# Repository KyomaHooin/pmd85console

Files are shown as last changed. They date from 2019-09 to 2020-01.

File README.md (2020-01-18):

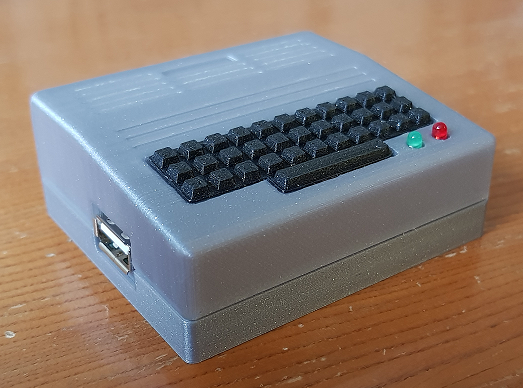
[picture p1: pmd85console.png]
CONSOLE console


DESCRIPTION

Raspberry Pi 1A+ Tesla PMD-85 retro console powered by modified Petr Tůma <a href="https://github.com/ceresek/simpmd">simpmd</a> (c) 2008.

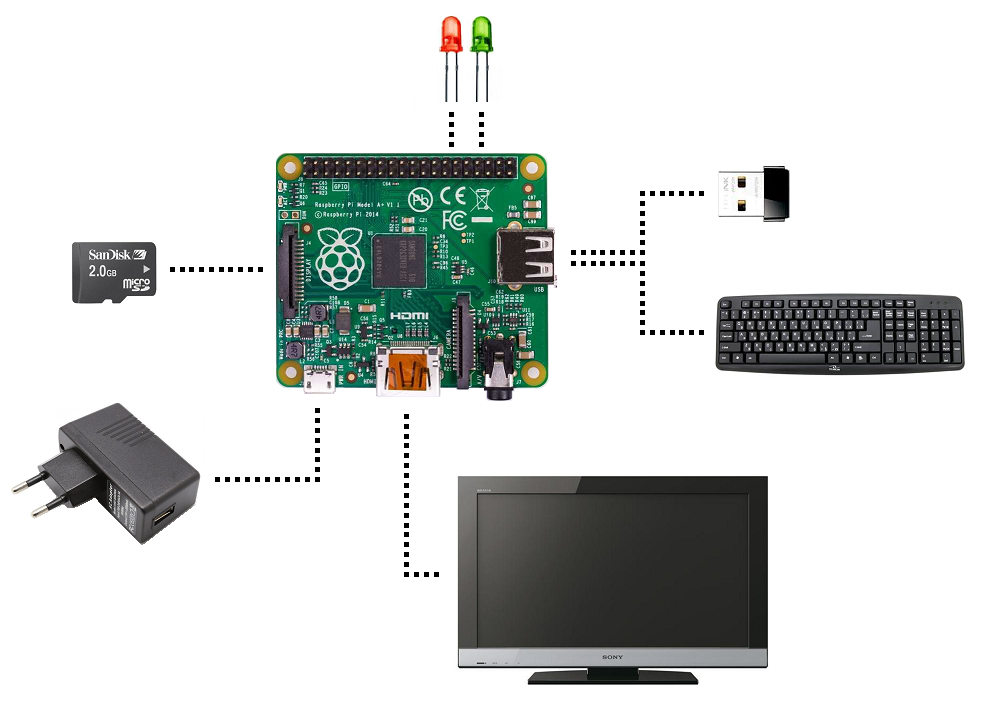
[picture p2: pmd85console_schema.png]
SCHEMA schema


SCREEN

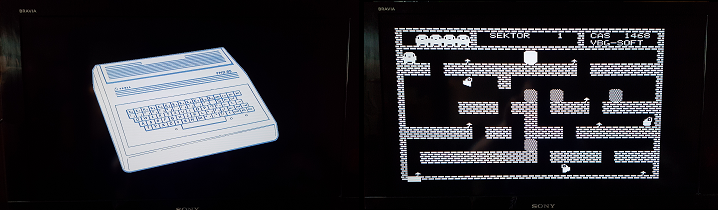
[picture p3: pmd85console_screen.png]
SCREEN screen


TODO

- Remove hardcoded paths.
- Menu scroll game preview.
- Fix sound.
- Fix window/renderer duplication.

BUG

- `snd flood alsa lib pcm.c:(snd_pcm_recover) underrun occured`
- `mesa loader: failed to retrieve device information`

HARDWARE

<pre>
1x <a target="_blank" href="http://rpishop.cz/248-raspberry-pi-1a">Raspberry</a> (1A+)
1x <a target="_blank" href="https://www.ges.cz/cz/usb-napajec-napajeci-adapter-mw-5v-1-2a-sun-usb-GES07507424.html">Power adapter</a> (5V 1.2A)
1x <a target="_blank" href="https://www.mironet.cz/edimax-wireless-nano-usb-20-adapter-80211n-150mbps-sw-wps+dp117994/">USB Wifi dongle</a> (RTL8188CUS/50-75mA)
1x <a target="_blank" href="https://www.czc.cz/gembird-cablexpert-kabel-hdmi-hdmi-0-5m-1-4-m-m-stineny-zlacene-kontakty-cerna/248060/produkt">HDMI cable</a> (0.5m)
1x <a target="_blank" href="https://www.alza.cz/roline-usb-2-0-usb-am-micro-usb-bm">Micro USB cable</a> (1m)
1x <a target="_blank" href="https://www.aliexpress.com/item/New-High-Quality-USB-To-TTL-Serial-Module-FTDI-FT232RL-USB-3-3V-5V-To-TTL/32971767031.html">USB FTDI TTL/UART</a> (3.3V 6-pin)
1x MicroSD (2GB)
1x Keyboard (Chicony KU-0108s/100mA)
1x <a target="_blank" href="https://www.ges.cz/cz/l-934gd-GES10700054.html">Green LED</a> (3mm 10mA 2.2V)
1x <a target="_blank" href="https://www.ges.cz/cz/l-934id-GES10701762.html">Red LED</a> (3mm 10mA 2V)
1x <a target="_blank" href="https://www.ges.cz/cz/rm0207-120r-1-GES05300318.html">Resistor 120R</a>
1x <a target="_blank" href="https://www.ges.cz/cz/rm0207-150r-1-GES05300319.html">Resistor 150R</a>
1x <a target="_blank" href="https://www.ges.cz/cz/bls-02-GES06614037.html">BLS 02</a>
2x <a target="_blank" href="https://www.ges.cz/cz/bls-01-GES06614525.html">BLS 01</a>
4x <a target="_blank" href="https://www.ges.cz/cz/bls-contacts-GES06614047.html">BLS contact</a>
1x <a target="_blank" href="https://www.ges.cz/cz/liyv-14-bl-GES06913880.html">Copper Wire</a> (0.14mm 1m)
4x <a target="_blank" href="https://www.ges.cz/cz/esst-m2-2x6-GES06814889.html">Screw</a> (M2.2x6mm)
</pre>

RPI

<pre>
wget --no-check-certificate https://downloads.raspberrypi.org/raspbian_lite_latest
# umount & write SD card / SD reader[!]
umount /dev/sdX[12] 2>/dev/null
unzip -p 2018-11-13-raspbian-stretch-lite.zip | dd of=/dev/sdX bs=4M

touch /boot/ssh
cat << EOF >> /boot/wpa_supplicant.conf
country=CZ
ctrl_interface=DIR=/var/run/wpa_supplicant GROUP=netdev
update_config=1
network={
	ssid="Wireless LAN"
	scan_ssid=1
	psk="cleartext"
	key_mgmt=WPA-PSK
}
EOF

raspi-config > Advanced > GL Driver > Enable Fake KMS

apt-get update
apt-get install libgl1-mesa-dri

raspi-config > Advanced > GPU mem > 128
raspi-config > Advanced > Overclocking > Medium

dphys-swapfile swapoff
dphys-swapfile uninstall

systemctl disable avahi-daemon bluetooth paxctld rsync triggerhappy triggerhappy.socket nfs-client.target \
                  systemd-timesyncd apt-daily apt-daily.timer apt-daily-upgrade apt-daily-upgrade.timer \
                  dphys-swapfile networking dhcpcd ssh getty@tty1 rc-local wifi-country keyboard-setup \
                  alsa-restore systemd-rfkill

cp raspberry/pmd85.service /etc/systemd/system/
systemctl enable pmd85.service

apt-get install vim mc ntpdate

/etc/fstab:
tmpfs	/tmp	tmpfs	defaults,noatime,nosuid,size=5m	0	0
tmpfs	/var/log	tmpfs	defaults,noatime,nosuid,mode=0755,size=5m	0	0

/etc/dhcpcd.conf:
interface wlan0
static ip_address=192.168.0.85/24
static routers=192.168.0.1
static domain_name_servers=xx.xx.xx.xx xx.xx.xx.xx
</pre>

UART

<pre>
3.3V UART => | x | x | GND | TX | RX | ..
             | x | x |  x  | x  | x  | ..

minicom -D /dev/ttyUSB0 -b 115200

[Ctrl] > [A] > [Z] > [O] > Serial port setup > [F]low control > Off
</pre>

LED

<pre name="led">
.. |  x  | x | x | x |  x  | x | x | x | GND | 16 | x | x |
.. | 3v3 | x | x | x | GND | x | x | x |  x  | x  | x | x |

           [RED]                    [GREEN]
            | |                       | |
     150R --  |                120R --  |
     [BGB]     -- 3.3V[17]     [BRB]     -- GPIO16[36]
       |                         |
      GND[25]                   GND[34]

/boot/config.txt:
# PWR LED(disable onboard)
dtparam=pwr_led_trigger=none
dtparam=pwr_led_activelow=off

# ACT LED GPIO16[36]
dtparam=act_led_gpio=16
dtparam=act_led_trigger=cpu
</pre>

PLYMOUTH

<pre>
apt-get install plymouth plymouth-themes -> 0.9.4-1.1(Buster)

cp -r theme-pmd85 /usr/share/plymouth/themes/

plymouth-set-default-theme -R theme-pmd85

/usr/share/plymouth/plymouthd.defaults:
DeviceTimout=10

systemctl disable plymouth-start -> Shutdown/reboot only.

/boot/cmdline.txt:
logo.nologo quiet splash plymouth.ignore-serial-consoles vt.global_cursor_default=0

/boot/config.txt:
boot_delay=0
</pre>

SDL2

<pre>
wget --no-check-certificate https://www.libsdl.org/release/SDL2-2.0.9.tar.gz

apt-get install libgles2-mesa-dev libgbm-dev libudev-dev libasound2-dev liblzma-dev

autogen.sh
./configure --enable-video-kmsdrm --disable-video-opengl --disable-video-x11 --disable-video-rpi
make
make install

wget --no-check-certificate https://www.libsdl.org/projects/SDL_ttf/release/SDL2_ttf-2.0.15.tar.gz
autogen.sh
./configure
make
make install
</pre>

SIMPMD

<pre>
make clean
make
</pre>

FILE

<pre>
                buster/ - Raspbian "Buster" install instructions by Jozef Říha - <a href="https://github.com/jose1711">jose1711</a>.
              openscad/ - 3D printable retro case.
             raspberry/ - Raspbery support scripts.
                simpmd/ - Modified SDL2 PMD-85 emulator source code by Petr Tůma (c) 2008.
           theme-pmd85/ - Splash Plymouth theme.

       pmd85console.png - Retro console final.
pmd85console_schema.png - Retro console schematics.
      atari-classic.ttf - TTF font by Mark Simonson (c) 2016.
</pre>

SOURCE

https://github.com/KyomaHooin/pmd85console

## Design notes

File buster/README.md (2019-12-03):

Install Raspbian using Noobs (https://www.raspberrypi.org/downloads/noobs/)
<pre>
# do these steps on a Linux system with an SD card inserted into a card reader
# all data on the card will be erased thus make sure you have a backup!
# at least 8GB SD card is recommended

# get the latest raspbian lite
wget https://downloads.raspberrypi.org/raspbian_lite_latest

# check target device (sd card) and set target variable accordingly
lsblk | grep ^sd
target=sdXY
sudo umount /dev/${target}*
unzip -p raspbian_lite_latest | pv | sudo dd of=/dev/${target} bs=4M
sudo mount /dev/${target}1 /mnt
sudo touch /mnt/ssh
# configure wifi if wired ethernet is not present
cat << EOF >> /mnt/wpa_supplicant.conf
country=CZ
ctrl_interface=DIR=/var/run/wpa_supplicant GROUP=netdev
update_config=1
network={
ssid="Wireless LAN"
scan_ssid=1
psk="cleartext"
key_mgmt=WPA-PSK
}
EOF
sudo umount /mnt
# remove the card from the reader, put into Raspi and boot from it
</pre>
Recompile SDL2 with KMS support
<pre>
# log in to raspberry pi (user: pi, password: raspberry) via SSH
# and change default password
passwd

sudo vi /etc/apt/sources.list
# uncomment deb-src in /etc/apt/sources.list

# do system update
sudo apt-get update
sudo apt-get upgrade
# install packages necessary to rebuild SDL with KMS enabled
sudo apt-get install devscripts build-essential libgbm-dev libgl1-mesa-dri git
sudo apt-get build-dep libsdl2

# install vim, mc and ntpdate (optional)
apt-get install vim mc ntpdate

# pull libsdl2 sources and rebuild
apt-get source libsdl2
cd libsdl2*/
sed -i '/enable-video-wayland/s/$/ --enable-video-kmsdrm --disable-video-opengl --disable-video-x11 --disable-video-rpi/' debian/rules
debuild -- clean
debuild -us -uc

# install KMS-enabled libsdl2
sudo dpkg -i ../libsdl2*.deb
sudo apt-mark hold sdl2-2.0.0 libsdl2-doc
</pre>
Performance tuning
<pre>
# disable swap
dphys-swapfile swapoff
dphys-swapfile uninstall

# turn-off unnecessary services
systemctl disable avahi-daemon bluetooth paxctld rsync triggerhappy triggerhappy.socket nfs-client.target \
                  systemd-timesyncd apt-daily apt-daily.timer apt-daily-upgrade apt-daily-upgrade.timer \
                  dphys-swapfile rc-local wifi-country keyboard-setup systemd-rfkill getty@tty1 exim4

# in case you have a chance to use UART for debugging, disable networking for faster boot
systemctl disable networking dhcpcd ssh systemd-timesyncd wpa_supplicant
</pre>
Additional configuration
<pre>
# Enable fake KMS
sudo raspi-config # > Advanced > GL Driver > Enable Fake KMS

# Change memory split and overclock
sudo raspi-config # > Advanced > GPU mem > 128
sudo raspi-config # > Overclocking > Medium

# use /tmp and /var/log as in-memory filesystems
echo "
tmpfs    /tmp      tmpfs    defaults,noatime,nosuid,size=5m            0  0
tmpfs    /var/log  tmpfs    defaults,noatime,nosuid,mode=0755,size=5m  0  0
" | sudo tee -a /etc/fstab

# reboot
</pre>
Compile and install simpmd
<pre>
# clone pmd85console project
git clone https://github.com/KyomaHooin/pmd85console.git

# compile modified simpmd
cd pmd85console/simpmd
# install dependencies
sudo apt install libghc-sdl2-ttf-dev
make PMD_BUILD=RELEASE PMD_SHARE=/usr/share/simpmd/

sudo cp bin/mem2raw bin/ptp2raw bin/rawinfo bin/simpmd /usr/bin
sudo install -dm755 /usr/share/simpmd
sudo cp data/roms/M* /usr/share/simpmd
sudo cp data/font/atari-classic.ttf /usr/share/simpmd
sudo cp data/logo/* /usr/share/simpmd
sudo cp data/tapes/games-pmd1/* /usr/share/simpmd
sudo cp data/tapes/games-pmd2/* /usr/share/simpmd
</pre>
Install Plymouth and customize boot
<pre>
sudo apt-get install plymouth plymouth-themes
sudo cp -r ~/pmd85console/theme-pmd85 /usr/share/plymouth/themes/
sudo plymouth-set-default-theme -R theme-pmd85
sudo sed -i '/DeviceTimeout=/s/.*/DeviceTimeout=10/' /usr/share/plymouth/plymouthd.defaults
sudo sudo systemctl disable plymouth-start
sudo sed -i '1s/$/ logo.nologo quiet splash plymouth.ignore-serial-consoles vt.global_cursor_default=0/' /boot/cmdline.txt
echo "boot_delay=0" | sudo tee -a /boot/config.txt
sudo cp ~/pmd85console/raspberry/pmd85.service /etc/systemd/system
sudo systemctl enable pmd85.service
</pre>

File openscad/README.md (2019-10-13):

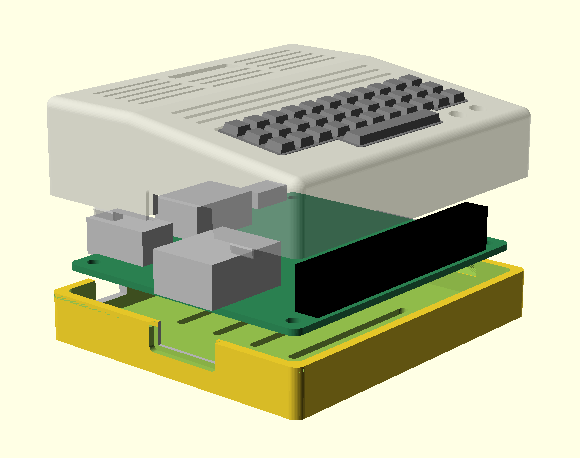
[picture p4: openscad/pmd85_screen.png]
CASE case


DESCRIPTION

Raspberry Pi 1A+ PMD-85 retro console 3D case.

FILES

<pre>
pmd85_bottom.stl - Case bottom part STL file.
   pmd85_top.stl - Case top part STL file.
    keyboard.stl - Keyboard STL file.

      pmd85.scad - Main 3D case.
        rpi.scad - Raspberry 1A+ model.
        mod.scad - Model functions.

pmd85_screen.png - Model screenshot.
</pre>

SOURCE

https://github.com/KyomaHooin/pmd85console

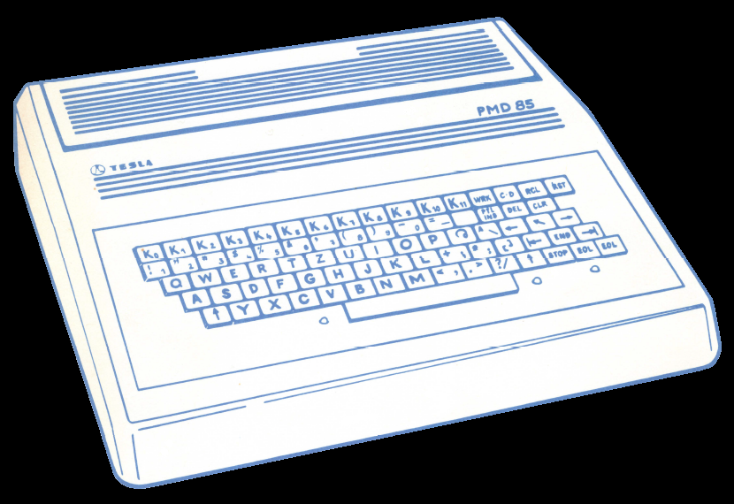
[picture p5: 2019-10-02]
theme-pmd85/pmd85_830_570.png

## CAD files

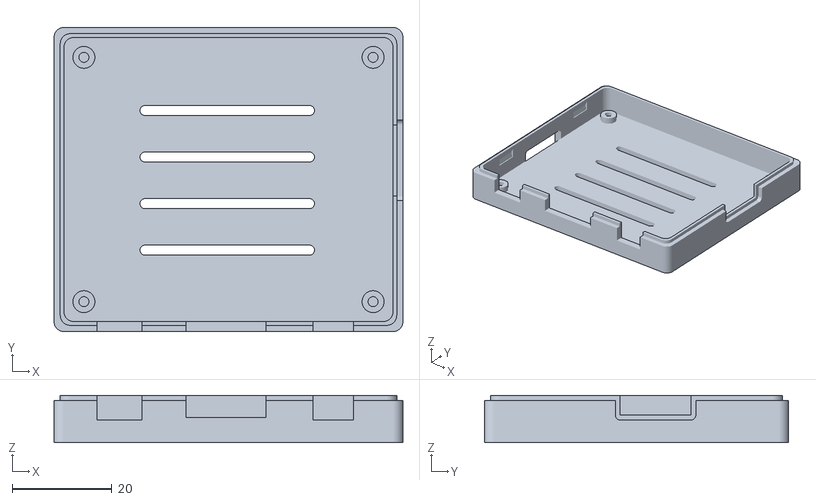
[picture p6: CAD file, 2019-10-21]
openscad/pmd85_bottom.stl
70.0 x 61.0 x 9.47

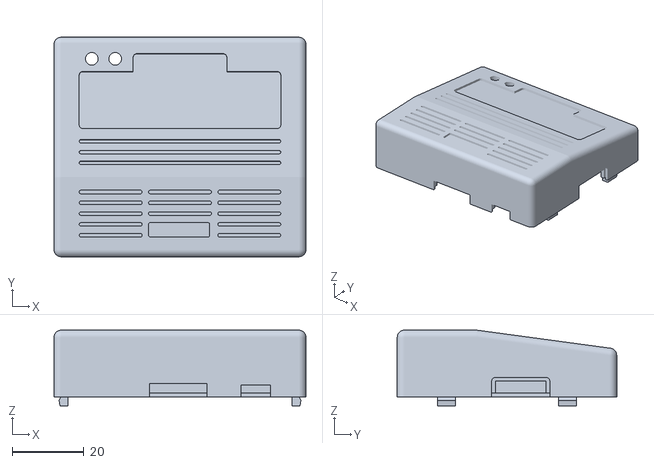
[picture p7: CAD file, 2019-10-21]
openscad/pmd85_top.stl
70.0 x 61.0 x 21.0

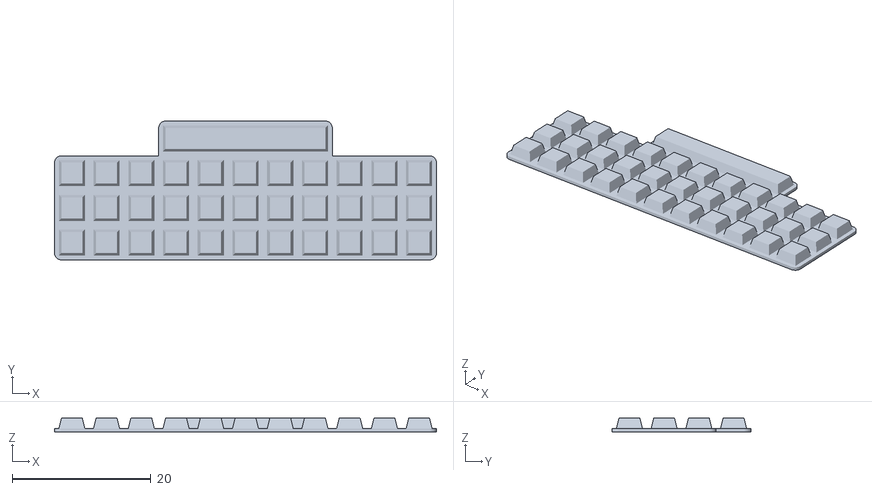
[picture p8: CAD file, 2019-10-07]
openscad/keyboard.stl
55.0 x 20.0 x 2.00

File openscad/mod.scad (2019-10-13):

//
// PMD-85 retro console mods
//

module bottom_hull(x,y,z) {
    hull() {
        cylinder(r=2,h=z);
        translate([x,0,0]) cylinder(r=2,h=z);
        translate([x,y,0]) cylinder(r=2,h=z);
        translate([0,y,0]) cylinder(r=2,h=z);
    }
}

module bottom_base() {
    difference() {
            bottom_hull(bottomX,bottomY,bottomHeight+1);// +1 = lip lock cut
            translate([bottomThick,bottomThick,bottomThick]) bottom_hull(bottomX-4,bottomY-4,bottomHeight+1);// +1 = lip lock cut
        }
    }

module bottom_lip_lock() {
    difference() {
        bottom_hull(bottomX,bottomY,1);
        translate([1.25,1.25,-1]) bottom_hull(bottomX-2.5,bottomY-2.5,3);
    }
}

module top_lip_lock() {
        translate([0.75,0.75,0]) bottom_hull(bottomX-1.5,bottomY-1.5,1);
}

module bottom_vent() {
    hull() {
        cylinder(r=1,h=2*bottomThick);
        translate([bottomX/2,0,0]) cylinder(r=1,h=2*bottomThick);
    }
}

module bottom_mount(offsetX,offsetY,Thick) {
    difference() {
        translate([offsetX, offsetY, Thick]) cylinder(h=bottomMountHeight, d=bottomMountDia);
        translate([offsetX, offsetY, Thick-1]) cylinder(h=bottomMountHeight+2, d=2);
    }
}

module sd_lip() {
    translate([0,0,cardHeight+bottomThick])
    rotate([0,90,0])
    hull() {
      cylinder(r=1,h=3);
      translate([0,cardWidth,0]) cylinder(r=1,h=3);
      translate([0,-1,0])cube([cardHeight+bottomThick,cardWidth+2,3]);
    }
}


module usb_lip(){
    rotate([90,0,90])
    hull() {
        cylinder(r=1,h=2);
        translate([usbWidth,0,0]) cylinder(r=1,h=2);
        translate([usbWidth,usbHeight,0]) cylinder(r=1,h=2);
        translate([0,usbHeight,0]) cylinder(r=1,h=2);
    }
}

module top_poly(x,y,h1,h2,rom) {
    minkowski(){
        polyhedron(
            points= [
                [0,0,0], //0
                [x,0,0], //1
                [x,y,0], //2
                [0,y,0], //3
                [0,0,h1], //4
                [x,0,h1], //5
                [x,rom,h1], //6
                [x,y,h2], //7
                [0,y,h2], //8
                [0,rom,h1] //9
            ],
            faces = [
                [0,1,2,3], //bottom
                [4,5,1,0], //back
                [5,6,7,2,1], // left
                [7,8,3,2], // front
                [8,9,4,0,3], // right
                [4,9,6,5], // top-A
                [9,8,7,6] // top-B
            ]
        );
        sphere(2);
    }
}

module top_base() {
   difference() {
   top_poly(topX,topY,topBackHeight,topFrontHeight,topRom);// BASE
   translate([2,2,0])top_poly(topX-4,topY-4,topBackHeight-2,topFrontHeight-2,topRom-2);// FILL
   translate([-2,-2,-3])cube([topX+4,topY+4,3]);// CUT
   }
}

module key_poly(x1,y1,x2,y2,h) {
        polyhedron(
            points= [
                [0,0,0], //0
                [x1,0,0], //1
                [x1,y1,0], //2
                [0,y1,0], //3
                [(x1-x2)/2,(y1-y2)/2,h], //4
                [x2+(x1-x2)/2,(y1-y2)/2,h], //5
                [x2+(x1-x2)/2,y2+(y1-y2)/2,h], //6
                [(x1-x2)/2,y2+(y1-y2)/2,h], //7
            ],
            faces = [
                [0,1,2,3], //bottom
                [4,5,1,0], //back
                [5,6,2,1], // left
                [6,7,3,2], // front
                [7,4,0,3], // right
                [7,6,5,4], // top
            ]
        );
}

module kbd_slab() { //56x26
    minkowski() {
    union() {
        cube([54,14,1]);//key base 56x16cm
        translate([30/2,14,0]) cube([24,5,1]);//spacebar base 26x6mm
    }
    cylinder(r=1);
    }
}

module vent_slab() {// 55x1
    hull() {
        translate([0,0,0])cylinder(r=0.5);
        translate([55,0,0])cylinder(r=0.5);
    }
}

module vent_slab_short() {
    hull() {
        translate([0.5,0.5,0])cylinder(r=0.5);
        translate([17,0.5,0])cylinder(r=0.5);
    }
}

module vent_slab_big() {
    translate([0.5,0.5,0])
    minkowski() {
        cube([16,3,1]);
        cylinder(r=0.5);
    }
}

module clip_hole() {// 1x5x4
    translate([-0.5,0,-1.5])
    difference(){
    polyhedron(
        points = [
            [1,0,0],//0
            [1,6,0],//1
            [0+0.5,0,3],//2
            [0+0.5,6,3],//3
            [1,0,4],//4
            [1,6,4] //5
    ],
        faces = [
            [3,2,0,1],
            [3,1,5],
            [4,5,1,0],
            [2,4,0],
            [4,2,3,5]
    ]
    );
    translate([0,-1,0])cube([2,8,1.5]);
    }
}

module clip() {
    difference(){
    union() {
    translate([0,0,3])cube([2,5,8]);
    polyhedron(
        points = [
            [0,0,0],//0
            [0,5,0],//1
            [0,0,3],//2
            [2,0,3],//3
            [2,5,3],//4
            [0,5,3] //5
    ],
        faces = [
            [2,3,0],
            [3,4,1,0],
            [5,1,4],
            [2,0,1,5],
            [2,5,4,3]
    ]
    );
    translate([-1,0,7])
    polyhedron(
        points = [
            [1,0,0],//0
            [1,5,0],//1
            [0+0.5,0,1],//2
            [0+0.5,5,1],//3
            [1,0,4],//4
            [1,5,4] //5
    ],
        faces = [
            [4,0,2],
            [4,5,1,0],
            [3,1,5],
            [4,2,3,5],
            [2,0,1,3]
    ]
    );
    }
    translate([-1,-1,11-1.5])cube([4,7,2]);// clip cut
    }
}

module clip_back() {
    translate([2,0,11-1.5])// clip cut
    rotate([0,180,0]) clip();
}

module clip_front() {
    translate([0,5,11-1.5])// clip cut
        rotate([0,180,180]) clip();
}

module clip_hole_front() {
    clip_hole();
}

module clip_hole_back() {
    translate([0.5,6,0])
        rotate([0,0,180]) clip_hole();
}

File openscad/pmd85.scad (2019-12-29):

//
// Retro PMD-85 console printable 3D case.
//

include <mod.scad>;
include <rpi.scad>;

drawCaseBottom=0;
drawCaseTop=0;
drawPi=0;
drawKeyboard=0;
drawAll=1;

//--------------------------------------

$fn=50;

//--------------------------------------

bottomThick=2;
bottomX=piX+1;
bottomY=piY+1;
bottomMountHeight=1.75;
bottomMountDia=4.4;
bottomHeight=bottomThick+bottomMountHeight+piThick+microHeight-0.5;

//--------------------------------------

topThick=bottomThick;
topX=piX+1;
topY=piY+1;
topBackHeight=25-bottomHeight;
topFrontHeight=20-bottomHeight;;
topRom=20;

angle = atan(5/37);
function angle_coord(x,a,thick) = -(5*x)/37 + 1025/37 + thick * tan(a)/sin(a);

//------------------------------
//
//KBD
//

module keyboard() {//55x15x2
    minkowski() {
      union() {
        cube([53,13,0.5]);//key base 55x15cm
        translate([30/2,14,0]) cube([23,4,0.5]);//spacebar base 25x5mm
      }
    cylinder(r=1);
    }
    for (fx=[0:10])
        for (fy=[0:2])
            translate([-0.5+fx*5,-0.5+fy*5,1]) key_poly(4,4,3,3,2); // key 4x4mm
    translate([30/2-0.5,0.5+14,1])key_poly(24,4,23,3,2); // spacebar 24x4mm
}

//------------------------------
//
// TOP
//

module case_top() {
    union() {
    difference() {
    top_base();
    //RPI
    translate([0.5,0.5,-piThick-microHeight+0.5])rpi(edge=2);
    //KBD SLAB
    translate([(topX-55)/2+0.5,34.5,angle_coord(34.5,angle,-7.25)])
        rotate([-angle,0,0]) kbd_slab();
    //VENT SLAB SLIDE
    translate([(topX-55)/2,30,angle_coord(30,angle,-7.1)]) rotate([-angle,0,0]) vent_slab();
    translate([(topX-55)/2,27,angle_coord(27,angle,-7.1)]) rotate([-angle,0,0]) vent_slab();
    translate([(topX-55)/2,24,angle_coord(24,angle,-7.1)]) rotate([-angle,0,0]) vent_slab();
    //VENT SLAB TOP
    translate([(topX-56)/2,15.5,topBackHeight+1.25]) vent_slab_short();
    translate([(topX-56)/2,12.5,topBackHeight+1.25]) vent_slab_short();
    translate([(topX-56)/2,9.5,topBackHeight+1.25]) vent_slab_short();
    translate([(topX-56)/2,6.5,topBackHeight+1.25]) vent_slab_short();
    translate([(topX-56)/2,3.5,topBackHeight+1.25]) vent_slab_short();
    translate([(topX-56)/2+15+(54-30-15.5)/2,9.5,topBackHeight+1.25]) vent_slab_short();
    translate([(topX-56)/2+15+(54-30-15.5)/2,12.5,topBackHeight+1.25]) vent_slab_short();
    translate([(topX-56)/2+15+(54-30-15.5)/2,15.5,topBackHeight+1.25]) vent_slab_short();
    translate([(topX-56)/2 + 54-15.5,15.5,topBackHeight+1.25]) vent_slab_short();
    translate([(topX-56)/2 + 54-15.5,12.5,topBackHeight+1.25]) vent_slab_short();
    translate([(topX-56)/2 + 54-15.5,9.5,topBackHeight+1.25]) vent_slab_short();
    translate([(topX-56)/2 + 54-15.5,6.5,topBackHeight+1.25]) vent_slab_short();
    translate([(topX-56)/2 + 54-15.5,3.5,topBackHeight+1.25]) vent_slab_short();
    translate([(topX-56)/2 +15+(54-30-15.5)/2,3.5,topBackHeight+1.25]) vent_slab_big();
    //LED HOLE
    translate([15,53,10]) cylinder(d=3.5,h=10);
    translate([8.5,53,10]) cylinder(d=3.5,h=10);
    // USB LIP
    translate([topX+1.25,piY-usbY-usbWidth+1,-microHeight+0.5+0.5]) usb_lip();
    //LIP LOCK
    top_lip_lock();
    }
    // CLIP
    translate([0-0.1,topY/4-5,-2.5])clip_front();
    translate([0-0.1,topY-topY/4,-2.5])clip_front();
    translate([topX-2+0.1,topY/4-5,-2.5])clip_back();
    translate([topX-2+0.1,topY-topY/4,-2.5])clip_back();
    }
    //KBD
    //color("grey")
    //translate([(topX-53)/2,35,angle_coord(35,angle,-8)]) rotate([-angle,0,0]) keyboard();
}

//------------------------------
//
// BOTTOM
//

module case_bottom() {
    difference() {
        //BASE
        bottom_base();
        //VENT
        for (vspace=[1:4])
            translate([piX/4,vspace*piY/6+5,-1]) bottom_vent();
        //SD LIP
        translate([-bottomThick-1,(bottomY-cardWidth)/2,0]) sd_lip();
        //RPI
        translate([0.5,0.5,bottomThick+bottomMountHeight]) rpi(edge=2);
        //CLIP HOLE
        translate([-1+0.5,bottomY/4-5.5,bottomHeight-2.5])clip_hole_front();
        translate([-1+0.5,bottomY-bottomY/4-0.5,bottomHeight-2.5])clip_hole_front();
        translate([bottomX,bottomY/4-5.5,bottomHeight-2.5])clip_hole_back();
        translate([bottomX,bottomY-bottomY/4-0.5,bottomHeight-2.5])clip_hole_back();
        // USB LIP
        translate([bottomX+0.75,piY-usbY-usbWidth+1,bottomThick+bottomMountHeight+piThick+0.5]) usb_lip();
        //LIP LOCK
        translate([0,0,bottomHeight]) bottom_lip_lock();
        translate([0.5,-microWidth/2,bottomHeight-microHeight/2])// MiroUSB fix
            translate([microX, -microOverHang, piThick-0.5])
                cube([microLength, microWidth, microHeight+1]);
    }
    // BOTTOM MOUNT
    bottom_mount(piHoleOffset+0.5, piHoleOffset+0.5, bottomThick);
    bottom_mount(bottomX-piHoleOffset-0.5,piHoleOffset+0.5, bottomThick);
    bottom_mount(piHoleOffset+0.5, bottomY-piHoleOffset-0.5, bottomThick);
    bottom_mount(bottomX-piHoleOffset-0.5, bottomY-piHoleOffset-0.5, bottomThick);
}

//------------------------------
//
// DISPLAY
//

if (drawCaseTop) { case_top(); }
if (drawCaseBottom) { case_bottom(); }
if (drawPi) { rpi(); }

if (drawKeyboard) {
    difference() {
        translate([0,0,-1])keyboard();
        translate([-2,-2,-2]) cube([58,22,2]);
    }
}

if (drawAll) {
    case_bottom();
    translate([0.5,0.5,bottomThick+bottomMountHeight]) rpi();
    translate([0,0,bottomHeight]) case_top();
}

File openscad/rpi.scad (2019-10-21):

//
// Retro PMD-85 console printable 3D case.
//

$fn=50;

piX=65;
piY=56;
piThick=1.27;
piHoleDia=2.75;
piHoleOffset=3.5;

usbWidth=13.16+1;
usbLength=17.05+1;
usbHeight=9.1-piThick-0.5;
usbOverHang=1.84;
usbY=17.6;

avWidth=7.20+1;
avLength=15;
avHeight=7.47-piThick+1;
avOverHang=2.44;
avX=53.5-avWidth/2;

hdmiWidth=11.47;
hdmiLength=15.04+1;
hdmiHeight=7.86-piThick+0.5;
hdmiOverHang=1.59;
hdmiX=32-(hdmiLength/2);

microWidth=5.59;
microLength=8.04+1;
microHeight=4.22-piThick+1;
microOverHang=1.9;
microX=10.6-(microLength/2);

cardWidth=13.04+1;
cardLength=17.18;
cardHeight=1.0+1;
cardOverHang=2.63;
cardY=piY/2-cardWidth/2;

gpioWidth=2.54*2;
gpioLength=20*2.54;
gpioHeight=6.10+2.5;
gpioX=(piX-gpioLength)/2;
gpioY=piY - gpioWidth -1.05;

module pi_hole() {
    cylinder(h=piThick+2, d=piHoleDia);
}

module rpi(edge=0) {
    color("seagreen")
    difference() {
        hull() {
            translate([2,2,0])cylinder(r=2,h=piThick);
            translate([piX-2,2,0])cylinder(r=2,h=piThick);
            translate([2,piY-2,0])cylinder(r=2,h=piThick);
            translate([piX-2,piY-2,0])cylinder(r=2,h=piThick);
        }
        translate([piHoleOffset, piHoleOffset, -1]) pi_hole();
        translate([piX-piHoleOffset, piHoleOffset, -1]) pi_hole();
        translate([piHoleOffset, piY-piHoleOffset, -1]) pi_hole();
        translate([piX-piHoleOffset, piY-piHoleOffset, -1]) pi_hole();
    }
    color("Silver") {
        // USB
        translate([piX-usbWidth-usbOverHang+edge, piY-usbY-usbWidth+0.5, piThick+0.5])
            cube([usbLength, usbWidth, usbHeight]);
        // HDMI
        translate([hdmiX, -hdmiOverHang-edge, piThick])
            cube([hdmiLength, hdmiWidth, hdmiHeight]);
        // AV
        translate([avX, -avOverHang-edge, piThick-0.5])
            cube([avWidth, avLength, avHeight]);
        // microUSB
        translate([microX, -microOverHang-edge, piThick-0.5])
            cube([microLength, microWidth, microHeight]);
        // microSD
        translate([-cardOverHang-edge, cardY, -cardHeight+0.5])
            cube([cardLength, cardWidth,cardHeight]);
    }
    // GPIO Headers
    color("black") {
        translate([gpioX, gpioY, piThick])
            cube([gpioLength, gpioWidth, gpioHeight]);
    }
}

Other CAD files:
openscad/rpi1Aplus.scad

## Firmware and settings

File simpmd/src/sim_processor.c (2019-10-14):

/*

SIM_PROCESSOR.C

Copyright 2008 Petr Tuma

Licensed under the Apache License, Version 2.0 (the "License");
you may not use this file except in compliance with the License.
You may obtain a copy of the License at

    http://www.apache.org/licenses/LICENSE-2.0

Unless required by applicable law or agreed to in writing, software
distributed under the License is distributed on an "AS IS" BASIS,
WITHOUT WARRANTIES OR CONDITIONS OF ANY KIND, either express or implied.
See the License for the specific language governing permissions and
limitations under the License.

*/

/* MODIFIED

 - Removed suspend/resume.
 - Sound commented out.
 - Reset termination token on CPU init.

*/

#include "sim_common.h"

#include <semaphore.h>


//--------------------------------------------------------------------------
// Synchronization Notes

// The processor simulation executes in an independent thread. The simulator
// needs to initialize the module before starting the module thread and
// terminate the module thread before shutting down the module.
//
// CPUInitialize - CPUStartThread - CPUTerminateThread - CPUShutdown
//
// Access to processor simulation is limited:
//
//  - External functions can be called but their execution will
//    wait until time synchronization occurs during simulation.
//
//  - Processor clock can be accessed atomically.


//--------------------------------------------------------------------------
// Asynchronous Execution Variables

static pthread_t sThread;

// Synchronization variables ...

static relaxed_bool bSuspend (false);
static sem_t sSignalSuspend;
static sem_t sSignalResume;

static relaxed_bool bTerminate (false);


//--------------------------------------------------------------------------
// Processor Status Variables

// Registers

// The registers are stored in unions that allow
// access to the two individual bytes as well
// as to the combined word ...

#if SDL_BYTEORDER == SDL_LIL_ENDIAN
#  define RegisterPairStruct(H,L) struct { byte L; byte H; }
#endif

#if SDL_BYTEORDER == SDL_BIG_ENDIAN
#  define RegisterPairStruct(H,L) struct { byte H; byte L; }
#endif

#define RegisterPairUnion(H,L) union { word Pair; RegisterPairStruct (H,L) One; } RegisterPair##H##L

static RegisterPairUnion (A,F);
static RegisterPairUnion (B,C);
static RegisterPairUnion (D,E);
static RegisterPairUnion (H,L);

#define RegAF (RegisterPairAF.Pair)
#define RegBC (RegisterPairBC.Pair)
#define RegDE (RegisterPairDE.Pair)
#define RegHL (RegisterPairHL.Pair)

#define RegA (RegisterPairAF.One.A)
#define RegF (RegisterPairAF.One.F)
#define RegB (RegisterPairBC.One.B)
#define RegC (RegisterPairBC.One.C)
#define RegD (RegisterPairDE.One.D)
#define RegE (RegisterPairDE.One.E)
#define RegH (RegisterPairHL.One.H)
#define RegL (RegisterPairHL.One.L)

static word RegPC;
static word RegSP;

// Individual flag variables, kept because it is easier to
// manipulate the individual variables than the flag register.
// Note that the two representations of flags are not kept
// synchronized, rather, individual flag variables take
// precendence over the flag register ...

static bool FlagS;
static bool FlagZ;
static bool FlagH;
static bool FlagP;
static bool FlagC;


//--------------------------------------------------------------------------
// Helper Variables

static bool abParity [256];


//--------------------------------------------------------------------------
// Helper Functions

// These are mostly inline functions rather than
// macros to avoid evaluating arguments multiple
// times.

/// Reads a byte from simulated memory array
inline byte MemReadByte (word iAddr)
{
  return (abMemoryData [iAddr]);
}

/// Reads a word from simulated memory array
inline word MemReadWord (word iAddr)
{
  return (MemReadByte (iAddr) + ((word) MemReadByte (iAddr + (word) 1) << 8));
}

/// Writes a byte to simulated memory array if it is writable.
inline void MemWriteByte (word iAddr, byte iData)
{
  if (abMemoryMask [iAddr]) abMemoryData [iAddr] = iData;
}

/// Writes a word to simulated memory array if it is writable.
inline void MemWriteWord (word iAddr, word iData)
{
  MemWriteByte (iAddr, iData);
  MemWriteByte (iAddr + (word) 1, iData >> 8);
}

/// Pushes a word onto the stack in the simulated memory array.
inline void MemPushWord (word iData)
{
  RegSP -= 2;
  MemWriteWord (RegSP, iData);
}

/// Pops a byte from the stack in the simulated memory array.
inline byte MemPopByte ()
{
  return (MemReadByte (RegSP ++));
}
/// Pops a word from the stack in the simulated memory array.
inline word MemPopWord ()
{
  byte iLow = MemPopByte ();
  byte iHigh = MemPopByte ();
  return (iLow + ((word) iHigh << 8));
}

/// Fetches a byte from simulated memory array at PC and shifts PC.
inline byte MemFetchByte ()
{
  return (MemReadByte (RegPC ++));
}
/// Fetches a word from simulated memory array at PC and shifts PC.
inline word MemFetchWord ()
{
  byte iLow = MemFetchByte ();
  byte iHigh = MemFetchByte ();
  return (iLow + ((word) iHigh << 8));
}


/// Expands its argument with all registers.
#define InstAllRegisters(I)                     \
  I (B)                                         \
  I (C)                                         \
  I (D)                                         \
  I (E)                                         \
  I (H)                                         \
  I (L)                                         \
  I (A)

/// Expands its arguments with all register pairs.
#define InstAllRegisterPairs(I)                 \
  I (BC,B)                                      \
  I (DE,D)                                      \
  I (HL,H)                                      \
  I (SP,SP)

/// Expands its arguments with all conditions.
#define InstAllConditions(I)                    \
  I (NZ,!FlagZ)                                 \
  I (Z,FlagZ)                                   \
  I (NC,!FlagC)                                 \
  I (C,FlagC)                                   \
  I (PO,!FlagP)                                 \
  I (PE,FlagP)                                  \
  I (P,!FlagS)                                  \
  I (M,FlagS)


/// Displays instructions when instruction tracing is enabled.
#ifdef DEBUG_CPU_TRACE_INSTRUCTIONS
#  define CPU_LOG_INSTRUCTION(X) DEBUG_LOG_PARTIAL (X)
#else
#  define CPU_LOG_INSTRUCTION(X)
#endif

/// Displays a formatted byte value.
#define CPU_LOG_FORMAT_BYTE(X) std::hex << std::uppercase << std::setfill ('0') << std::setw (2) << (int) X
/// Displays a formatted word value.
#define CPU_LOG_FORMAT_WORD(X) std::hex << std::uppercase << std::setfill ('0') << std::setw (4) << (int) X

#define CPU_LOG_INST_X(X)       CPU_LOG_INSTRUCTION (#X)

#define CPU_LOG_INST_B(X)       CPU_LOG_INSTRUCTION (#X " " << CPU_LOG_FORMAT_BYTE (MemReadByte (RegPC)))
#define CPU_LOG_INST_W(X)       CPU_LOG_INSTRUCTION (#X " " << CPU_LOG_FORMAT_WORD (MemReadWord (RegPC)))
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

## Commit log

2018-11-14 Remove gray frame.
2018-11-14 Remove border frame code.
2019-03-11 Thread, graphics update.
2019-07-27 Simpmd(Petr Tuma) init.
    [DUCHAN.G, MAGICK.G]
2019-09-02 Simpmd SDL2 develop branch.
    [DUCHAN.G, MAGICK.G]
2019-09-10 SCAD init.
    [pmd85_bottom.scad, pmd85_top.scad, rpi1Aplus.scad]
2019-09-10 Base code.
    [pmd85.scad, rpi1Aplus.scad]
2019-09-10 Git push origin master.
    [pmd85_bottom.scad, pmd85_top.scad]
2019-09-10 Model update.
    [fc.scad, pmd85.scad]
2019-09-10 Status LED.
2019-09-11 Runner, Manic+, cleanup.
    [DUCHAN.G, MAGICK.G]
2019-09-13 Fix case.
2019-09-13 Case logic fix.
2019-09-15 LED update.
2019-09-15 Image/frame spacing, typo.
2019-09-19 SCAD update.
    [keyboard.stl, pmd85.scad, rpi.scad]
2019-09-21 Framebuffer, sim_menu.c, menu.
2019-09-26 LED setup.
2019-09-26 Keyboard/slab update/cleanup.
    [mod.scad, pmd85.scad]
2019-09-27 Act LED cpu trigger.
2019-09-27 Size+1,SD lip, typo, cleanup.
    [mod.scad, pmd85.scad, rpi.scad]
2019-09-27 Cleanup, TODO.
    [pmd85.scad]
2019-09-27 Clip lock.
    [mod.scad, pmd85.scad]
2019-09-28 SCAD Bug fix, cleanup.
    [mod.scad, pmd85.scad, rpi.scad]
2019-09-28 SCAD typo,cleanup.
    [mod.scad, pmd85.scad, rpi.scad]
2019-09-28 Beta STL.
    [keyboard.stl, pmd85_bottom.stl, pmd85_top.stl]
2019-09-28 Lip lock, clip hole fix, poly fix.
    [mod.scad, pmd85.scad]
2019-09-28 Netfabb fixes.
    [mod.scad, pmd85.scad, pmd85_bottom.stl]
2019-09-30 Reset bTerminate token, cleanup.
    [sim_processor.c]
2019-10-01 Update screen, fix keyboard.
    [pmd85.scad]
2019-10-02 Raspberry scripts, typo, update.
2019-10-03 Slicer union fix.
    [pmd85.scad, pmd85_top.stl]
2019-10-05 Clip 0.5mm resize.
    [mod.scad, pmd85.scad, pmd85_bottom.stl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]
2019-10-07 Clip angle, top clip float fix.
    [keyboard.stl, mod.scad, pmd85.scad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]
2019-10-09 Micro USB cable.
2019-10-13 Fix microUSB regression, HDMI position, USB width and position.
    [rpi.scad]
2019-10-13 MicroUSB regression fix, clip 1.5mm cut.
    [mod.scad, pmd85.scad]
2019-10-13 Minor fix.
    [mod.scad]
2019-10-13 Led hole +0.25.
    [pmd85.scad]
2019-10-13 Bottom lip fix, USB lip.
    [mod.scad, pmd85.scad]
2019-10-13 Top fixes, code cleanup.
    [pmd85.scad, rpi.scad]
2019-10-13 Bottom, top STL update.
    [pmd85_bottom.stl, pmd85_top.stl]
2019-10-21 Cut USB height 0.5 top/bottom.
    [pmd85.scad, rpi.scad]
2019-10-21 STL update USB.
    [pmd85_bottom.stl, pmd85_top.stl]
2019-12-27 Thinner wire, LED size.
2019-12-29 Syntax, cleanup.
    [pmd85.scad]
